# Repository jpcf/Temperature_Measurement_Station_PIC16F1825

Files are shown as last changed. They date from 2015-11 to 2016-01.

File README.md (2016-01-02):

## Temperature Measurement Station

Electronic Systems class Final Project. Consists of a Temperature/HeartRate monitor based on the PIC16F1825 uController. It uses a Nokia5110 LCD matrix as a means to display.

On the `include` folder, you can find a library that interfaces the display (`lib_LCD_Nokia5110`) and another for the 1-Wire Temperature Sensor (`ds18b20`). We also included a library that performs memory tests on all three memory types: RAM, ROM and EEPROM (` lib_memtest_PIC16F1825`).

You are free to use this code in your projects, but **please refer the authors**, *José Fonseca* (me) and *Carlos Ferreira*, from the **University of Porto, Portugal**.

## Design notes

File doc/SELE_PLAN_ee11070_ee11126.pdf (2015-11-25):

# Fingertip Heartrate Measurement

## Carlos Ferreira (ee11070), Jos´e Fonseca (ee11126)

26-10-2015

The envisaged system will measure the heartrate using an infrared measurement sensor, the TCRT1000. The system’s main components are a TCRT1000 sensor, analog circuits, an 8-pin microcontroller, three 7-segment displays and shift-registers.

## 1 Project Overview

The TCRT1000 sensor outputs a current proportional to the infrared light, reflected by the blood. This way, everytime that there is a heartbeat, this reflection will be higher due to the higher concentration of blood. After this, the resulting waveform will be high-pass filtered to enhance the voltage peak that represents the heartbeat. This peak will be fed to a monostable 555 timer that, every time it is triggered by this peak, will produce a voltage pulse with a fixed duration, which will be captured by one of the micro-controller’s General Purpouse Input/Outputs (GPIO).
The microcontroller will then process the incoming pulses and evaluate the inter-arrival time, and extrapolate the heartbeat from this information. Then, at fixed intervals, it will compute a value for the heartrate, and output each one of the 3 decimal digits (since a person’s heartbeat is generally between 60-200 beats per minute, we only need 3 digits to represent it) to three 7-segment displays. Each 7-segment display will have a shift-register that will keep the value stored in its intermediate memory, and they will be arranged in a daisy-chain fashion, connected to the MISO and MOSI interfaces of the microcontroller.
This arrangement can be better understood by observing the following figure.
TCRT1000 | High-Pass Filter

555 Monostable
Trigger (Pulse Generator)

GPIO
(Input)

MOSI

GPIO
(Output) MISO

uController

Shift Register | Shift Register | Shift Register

Data In

Data In | Data In
Data Out | Data Out
Data out OutputEn | OutputEn | OutputEn

7-Segment
LCD
(CENTS)

7-Segment
LCD
(DECS)

7-Segment
LCD
(UNITS)
7 | 7 | 7

## 2 Lab and Industrial prototype

The laboratory prototype will be developed using a PIC32MX120F032B from Microchip in a breadboard. This is already tested because it was used on other projects, so it won’t be necessary to debug this configuration (the basic PIC32MX120F032B IC and the discrete components necessary). The power supply is already designed (basically and 9v battery and a 3.3 voltage regulator). The analog circuitry will be mounted on the breadboard and we will test it with an oscilloscope to ensure correct behaviour.
The industrial prototype will use an 8-pin PIC16F18313 microcontroller. The power supply will be identical to the one used in the laboratory prototype. The remaining hardware is also ‘portable’, and, for that reason, it will be the same from the lab prototype.

## 3 Development Approach

Stages of Development

The first step will be the design of the analog circuitry that serves as the basis of the interface. This will include the dimensioning of the high-pass filter, calculating the appropriate gain to appropriately trigger the 555 timer – even when the pulse is relatively dim – and to calculate the appropriate 555 pulse duration, and the corresponding values for C and R that will define it.
This pulse will first actuate a LED and, after we are sure that is works appropriately, we will develop the microcontroller-side software, and debug the calculated heart-rate values, transferring them to a computer via its UART interface.
After this is done, we can start to develop the software for the 7-segment drivers, and the associated daisy-chain configuration, again debugging using the UART interface.
When both of these halves are complete, we will merge them together, and check if the system works as a whole. After this, we will finally develop a suite of software tests that will be embedded in the project, and will be run everytime the system is startup.

Software used and Organization Policies

We will use MPLABX as the Integrated Development Environment to develop the software for the microcontrollers, and also as a debugging platform. Cadsoft’s Eagle will be used to keep the project schematic updated, and to develop the final tentative board for a hypothetical final product.
Everytime we commit to a hardware component placement/design, we will update the Eagle schematic; this way, we will have a quick reference if some wire is inadvertly disconnected, and it will also be easier to design the PCB board at the end of the project. We will also keep a Git-Hub folder with all the schematics and source code of our project, where you will be able to keep up with the work that we are developing.

## 4 Component List

Component | Price (per unit) | # of units
TCRT1000 (http://pt.farnell.com/vishay-siliconix/tcrt1000/sensor-optical-4mm-transistor/dp/1470064) (IR Sensor) | e1.06 | 2
LD1117V33-DG (http://www.digikey.com/product-detail/en/LD1117V33-DG/497-12822-5-ND/3028553) (3.3 voltage regulator) | e0.71 | 2
PIC16F18313 (http://www.digikey.com/product-detail/en/PIC16F18313-I%2FP/PIC16F18313-I%2FP-ND/5033490) (microcontroller) | e0.69 | 2
LM555CNNS/NOPB-ND (http://www.digikey.com/product-detail/en/LM555CN%2FNOPB/LM555CNNS%2FNOPB-ND/6575) (555 timer) | e1.10 | 2
74HCT595N (http://eu.mouser.com/ProductDetail/NXP-Semiconductors/74HCT595N112/?qs=me8TqzrmIYXtbHcL2Ztc%2fQ%3d%3d) (shift-register) | e1.78 | 4
TDSL5160 (http://eu.mouser.com/ProductDetail/Vishay-Semiconductors/TDSL5160/) (7 segment display) | e1.90 | 3

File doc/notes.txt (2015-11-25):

--> A conexão a IR_CATHODE (pino 3 [4]) não é necessária, é feita internamente (cf página 5 da D.S.)

--> Os pinos 10-12 NÃO DEVEM ESTAR LIGADOS!

--> O address do dispositivo é fixo, e é o 0010_011x_b, em que 'x' é o bit
que define o modo de leitura ou escrita. Anyway, o endereço do 'escravo' é 0x13 

--> O registo dos resultados está no registo 7 e 8 (endereços 0x87 e 0x88), que
contém, respectivamente, o byte MAIS significativo (Reg7) e o MENOS significativo (Reg8)
--> O registo da ambient light está no registo 5 e 6 (endereçoes 0x85 e 0x86).

--> A stop condition entre write e reads consecutivos NÃO É obrigatória.
--> Também funciona  com repeated start!
--> Para ler registos subsequentes, não é necessário endereçá-los: basta endereçar o primeiro, e o register counter é incrementado automaticamente a cada comando de Read para o slave.

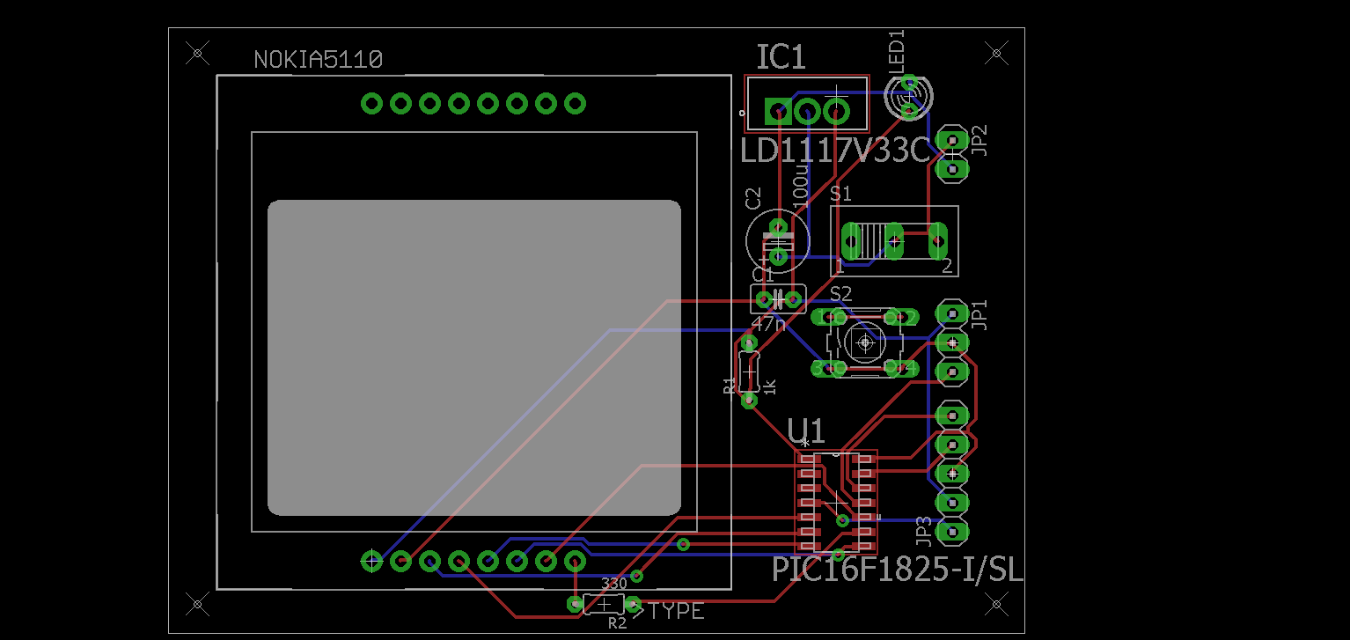
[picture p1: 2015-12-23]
sch/seleBoard.png

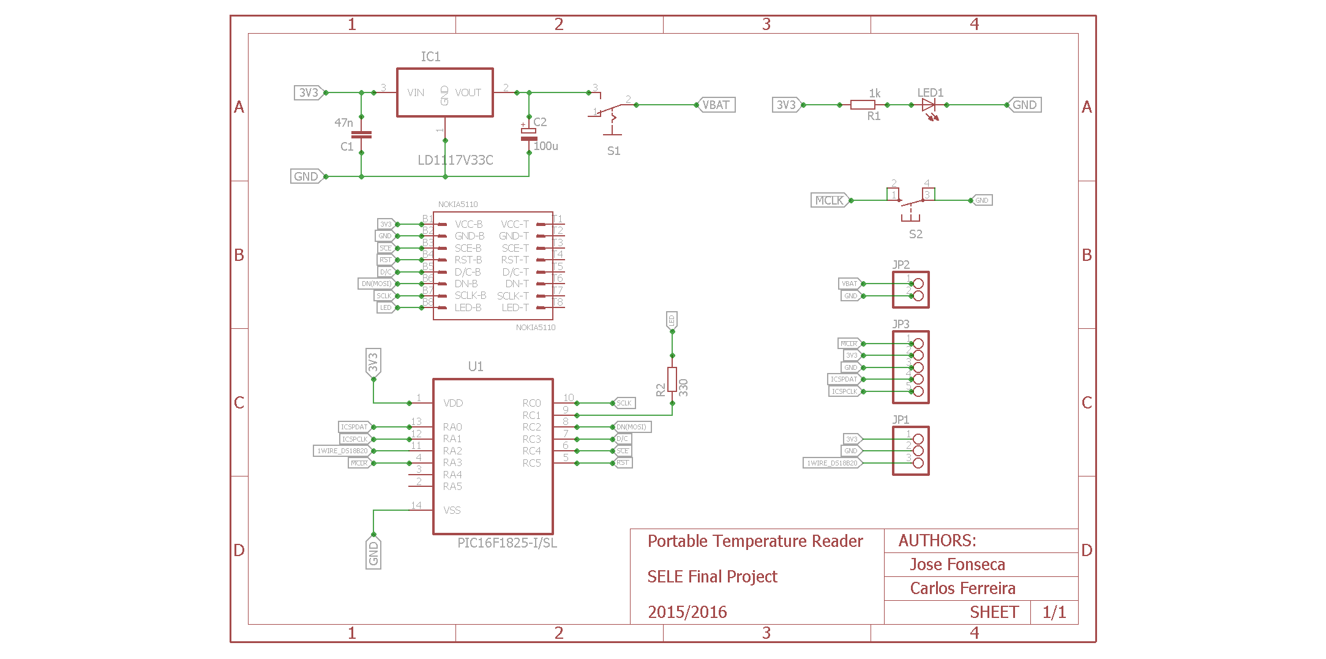
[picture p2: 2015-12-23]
sch/seleSchem.png

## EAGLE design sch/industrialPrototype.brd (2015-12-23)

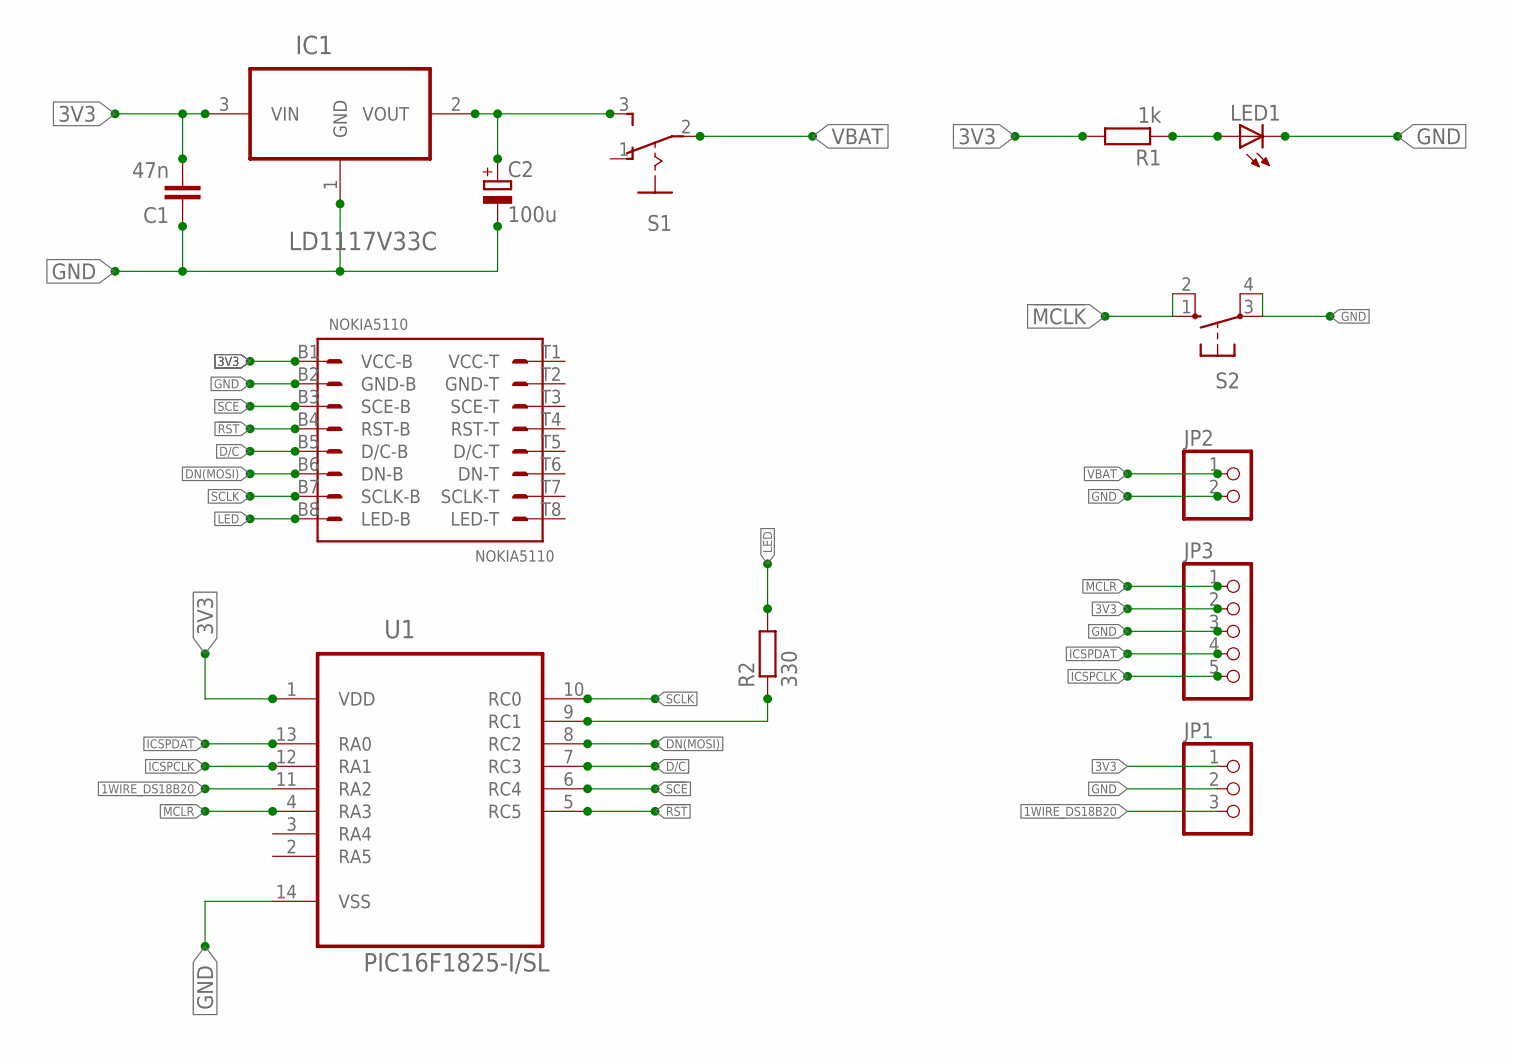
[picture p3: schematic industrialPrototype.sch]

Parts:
C1: 47n; C025-025X050
C2: 100u; E2,5-6
IC1: LD1117V33C; TO254P482X1024X3124-3P
JP1: PINHD-1X3; 1X03
JP2: PINHD-1X2; 1X02
JP3: PINHD-1X5; 1X05
LED1: LED3MM
NOKIA5110: NOKIA5110
R1: 1k; 0204/5
R2: 330; 0204/5
S1: 255SB
S2: 10-XX; B3F-10XX
U1: PIC16F1825-I/SL; SOIC127P600X175-14N

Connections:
1WIRE_DS18B20: JP1.3, U1.11 (RA2)
3V3: C1.2, IC1.3 (VIN), JP1.1, JP3.2, NOKIA5110.B1 (VCC-B), R1.2, U1.1 (VDD)
!MCLK!: S2.1 (S), S2.2 (S1)
!MCLR!: JP3.1, U1.4 (RA3)
!RST!: NOKIA5110.B4 (RST-B), U1.5 (RC5)
!SCE!: NOKIA5110.B3 (SCE-B), U1.6 (RC4)
D/C: NOKIA5110.B5 (D/C-B), U1.7 (RC3)
DN(MOSI): NOKIA5110.B6 (DN-B), U1.8 (RC2)
GND: C1.1, C2.-, IC1.1 (GND), JP1.2, JP2.2, JP3.3, LED1.K (C), NOKIA5110.B2 (GND-B), S2.3, S2.4 (P1), U1.14 (VSS)
ICSPCLK: JP3.5, U1.12 (RA1)
ICSPDAT: JP3.4, U1.13 (RA0)
LED: NOKIA5110.B8 (LED-B), R2.2
unnamed: LED1.A, R1.1
unnamed: R2.1, U1.9 (RC1)
SCLK: NOKIA5110.B7 (SCLK-B), U1.10 (RC0)
VBAT: C2.+, IC1.2 (VOUT), JP2.1, S1.2, S1.3 (S)

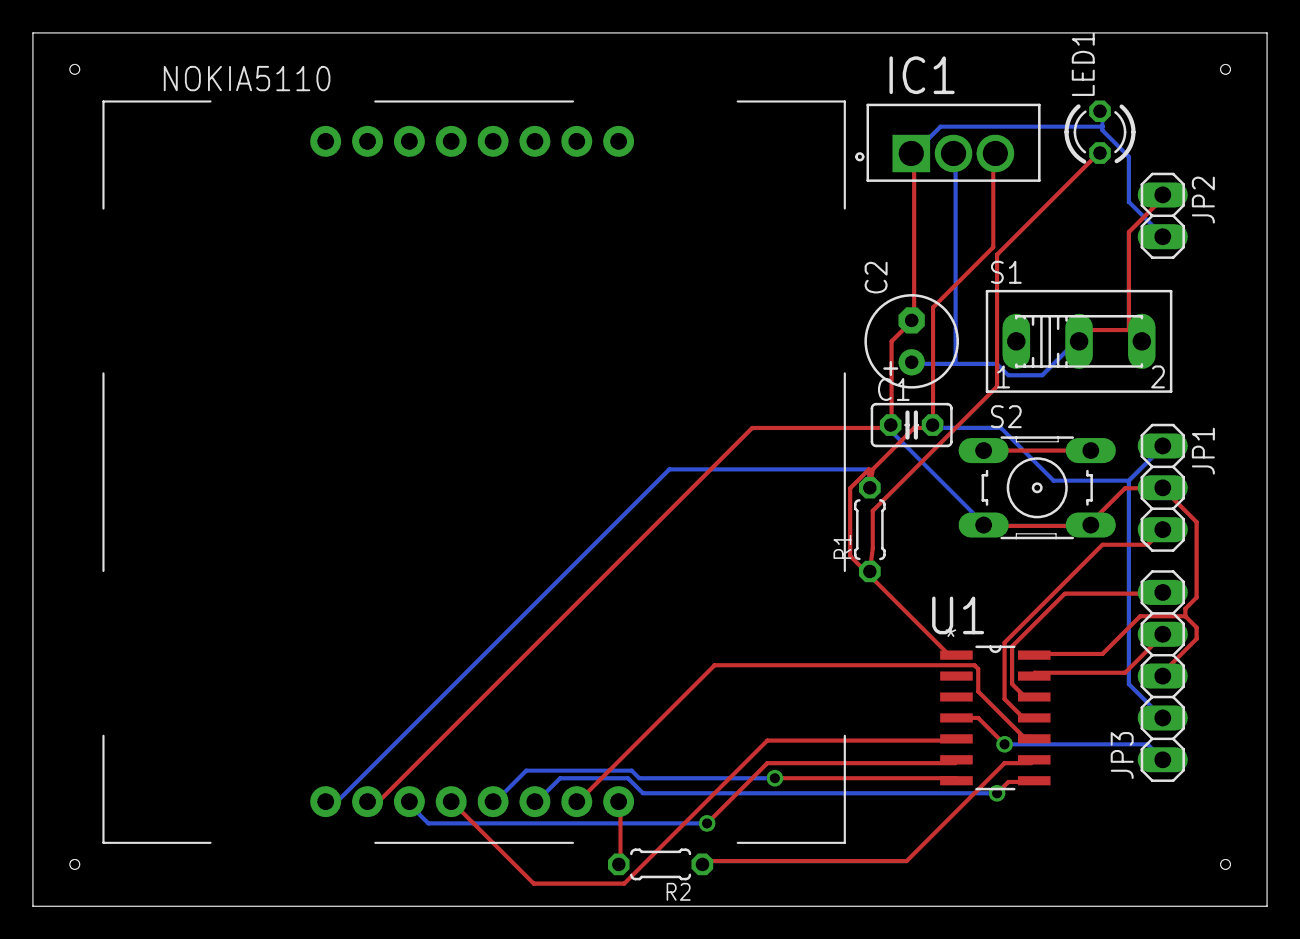
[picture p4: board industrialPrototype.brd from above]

Board: 2 copper layers, 74.9 x 53.0 mm, 13 parts (0 on the bottom side), 16 nets.

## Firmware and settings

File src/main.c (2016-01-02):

/*
Authors: José Pedro Fonseca, Carlos Ferreira, 2015
University of Porto, Portugal
*/

#include <stdio.h>
#include <stdlib.h>
#include <string.h>
#include <stdint.h>
#include <xc.h>
#include "../include/PIC16F1825_configs.h"
#include "../include/ds18b20.h"
#include "../include/lib_LCD_Nokia5110.h"
#include "../include/lib_memtest_PIC16F1825.h"
#include "../include/PIC16F1825_utils.h"

const char IMG[504] = {
0x08,
0xA2,
0x55,
0x08,
0x22,
0x04,
0x29,
0x02,
0x28,
0x12,
0x05,
0x28,
0x02,
0x14,
0x09,
0x22,
0x14,
0x00,
0x00,
0x22,
0x88,
0x55,
0x22,
0x08,
0x22,
0x09,
0x14,
0x22,
0x08,
0x05,
0x12,
0x28,
0x02,
0x29,
0x04,
0x12,
0x00,
0x00,
0xA2,
0x08,
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


int main(int argc, char** argv) {
    
    char tempStr[14];
    LCDcursor cursor;    
    /* ----- Device Initial Config ----- */
    pic16f1825_init();
    
    /* ------ LCD Initial Config ------- */
    initLCD();
    configLCD();
    
    /* ---------- RAM Testing ---------- */
    uint16_t RAMtest = memtest_MARCH_Cmin();
    LATC1 = 1;
    
    clearLCD(&cursor);
    sprintf(tempStr, "Memory Tests:");  
    printlnLCD(tempStr, strlen(tempStr), 2, &cursor);
    
    /* Returns 0x3000 if no Errors, otherwise returns the address of the first error */
    gotoXY(0, cursor.yPos+1);
    cursor.yPos += 1;
    
    if(0x3000 == RAMtest){
        sprintf(tempStr, "RAM Test OK!");  
        printlnLCD(tempStr, strlen(tempStr), 2, &cursor);
    }else {
        sprintf(tempStr, "!RAM @ 0x%04X", RAMtest);
        printlnLCD(tempStr, strlen(tempStr), 2, &cursor);
    }

    /* ---------- ROM Testing ---------- */
    uint8_t ROMtest = memtest_program_mem();
    if(ROMtest){
        sprintf(tempStr, "ROM Test OK!");  
        printlnLCD(tempStr, strlen(tempStr), 2, &cursor); 
    }else {
        sprintf(tempStr, "ROM Error!");  
        printlnLCD(tempStr, strlen(tempStr), 2, &cursor);
    }
    
    /* -------- EEPROM Testing -------- */
    if(memtest_eeprom(NULL)){
        sprintf(tempStr, "EEPROM Test OK!");  
        printlnLCD(tempStr, strlen(tempStr), 2, &cursor);
    }else {
        sprintf(tempStr, "EEPROM Error!");  
        printlnLCD(tempStr, strlen(tempStr), 2, &cursor);
    }
    
    uint8_t turn_on_times = read_eeprom(0);
    
    if(0xFF == turn_on_times) /* By default the EEPROM data in a given address is 0xFF */
        turn_on_times = 1;    /* This is the first time the circuit is powered up */
    else
        turn_on_times++;
    
    write_eeprom(0,turn_on_times);
    write_eeprom(255,turn_on_times ); /* update the checksum (last address of EEPROM) */
    
    sprintf(tempStr, "The circuit was powered %d times",turn_on_times);  
    printlnLCD(tempStr, strlen(tempStr), 2, &cursor);
    
    __delay_ms(3000);
    printImageLCD(IMG);
    __delay_ms(3000);

    set_precision_ds18b20(PRECISION_12);
    
    while(1){
        start_temp_measure_ds18b20();
        __delay_ms(1000);           /* Wait for temperature measurement */
        sprintf(tempStr, "Temp: %.2f", read_temp_ds18b20());
        gotoXY(0,2);
        cursor.yPos = 2;
        printlnLCD(tempStr, strlen(tempStr), 2, &cursor);
    }

    return (EXIT_SUCCESS);
}

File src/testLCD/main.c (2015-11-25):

#include <stdio.h>
#include <stdlib.h>
#include <stdint.h>
//#include <PIC16F1825.h>
#include <xc.h>

#pragma config WDTE = OFF // This disables the watchdog timer!

#define _XTAL_FREQ 4000000
#define DC    LATC3
#define SCE   LATC4
#define RST   LATC5
#define DIN   LATC2
#define SCK   LATC0

void TIMER2config (unsigned char comparePer, unsigned char preload,
                   unsigned char presc, unsigned char postsc) {
    PR2    = comparePer;  
    TMR2   = preload; 
    T2CON |= postsc | (presc<<3); 
}

void initLCD() {
    // Some initial configs on port C
    ANSELC &= 0x00; // All bits on port C are set to Digital I/O's
    TRISC  &= 0x00; // All bits on Port C are set to Outputs
    APFCON0 |= (1<<5); // Don't use special features on Pin RC3
    APFCON1 |= (1<<2); // Don't use special features on Pin RC3
    
    LATC = 0x00;
    
    // All pins are initialy idle (HIGH), except for DIN
    DC    = 1;
    SCE   = 1;
    RST   = 1;
    DIN   = 0;
    SCK   = 0;
    
    // Initial reset to the device
    __delay_ms(300);
    RST = 0;
    __delay_ms(300);
    RST = 1;
}

void sendByteLCD(unsigned char* buf, unsigned char dataCommand) {
    DC  = dataCommand;
    SCK = 0;
    __delay_us(1);
    SCE = 0;
    __delay_us(1);
    
    for(int i=0; i < 8; i++) {
        SCK = 0; // Clock goes idle
        
        // Since we send the MSB first, we mask bit 8 and we send its logical value
        (*buf) & 0b10000000 ? DIN = 1 : DIN = 0;  
        
        // Rising Edge of the Clock
        __delay_us(1);
        SCK = 1;
        __delay_us(1);
        
        // We shift the next bit
        (*buf) = ((*buf)<<1);
    }
    
    SCK = 0;
}

void printCharLCD(char c) {

}

void CLOCKconfig() {
    OSCCON  = 0x6A; //Sets the internal oscillator fosc = 4 MHz
    OSCSTAT = 0x00;
    OSCTUNE = 0x00;
}

void main(void) {
    
    unsigned char buf;
    
    CLOCKconfig();
    initLCD();
    
    buf = 0x21;
    sendByteLCD(&buf, 0);
    buf = 0xC0; // Set the Operation Voltage to a good value
    sendByteLCD(&buf, 0);
    buf = 0x07; // Set the TempCoef to 4
    sendByteLCD(&buf, 0);
    buf = 0x13; // Set Bias bits BSx. This way we get Mux of 1:48
    sendByteLCD(&buf, 0);
    buf = 0x20; // Normal set of controls
    sendByteLCD(&buf, 0);
    buf = 0x08; // Clears the screen
    sendByteLCD(&buf, 0);
    buf = 0x0C; // Normal Display Mode
    sendByteLCD(&buf, 0);
    
    LATC1 = 1;
    __delay_ms(1000);
    
    while(1) {
        buf = rand() % 256;
        sendByteLCD(&buf, 1);
        __delay_ms(1);
    }
    
}

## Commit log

2015-11-24 First Commit: The first prototype for the README.md file
2015-11-24 The test file for the LCD driver
2015-11-25 Now the LCD completely works, and is able to print data. Need to clean the file, separate the functions to another file, and find a suitable font
2015-11-26 Added font support to the Library, and a function to print a char that partially works
2015-11-28 Changed the testSPI.c file. Now prints the whole alphabet, but somehow starts filling blanks afterwards
2015-11-28 Added support to print lines, and go to a specified address. There are still some issues
2015-11-29 Added further printlnLCD function, and also corrected the pointer issue of the send_N_ByteLCD()
2015-11-29 Now makes use of the printlnLCD, and uses sprintf to format the string
2015-11-29 Now prints in hex format correctly
2015-12-02 Foram adicionados varios ficheiros. pic16f1825_configs .h e respectivo .c pic16f1825_utils.h e respectivo .c ds18b20.h e respectivo .c
    Foi alterado o lib_memtest_pic16f1825.c e respectivo .h em que se adicionou a função que testa a ROM
    Foi também adicionado o ficheiro /src/main.c que contem a funcao main
2015-12-02 ao ao pino usado no 1-wire que agora é o RA2 FOi retirado o _RC2_ dos nomes das funcões 1-wire
2015-12-02 The first sketch of the final executable. Only missing the integration with OneWire readings
    [main.c]
2015-12-03 Improved the main file and the graphics library. Still missing the sensor integration
    [main.c]
2015-12-03 Corrigido bug do teste da ROM
    [main.c]
2015-12-13 Foi adicionado o teste da EEPROM Foram adicionadas as funcoes eeprom_read e eeprom_write Foi adaptado o main para utilizar as novas funçoes
2015-12-15 Added the schematic. Still missing connections to temp sensor and other
    [industrialPrototype.sch]
2015-12-15 Schematic almost finished. Only temp sensor header missing
    [industrialPrototype.brd, industrialPrototype.sch]
2015-12-15 Added Programming Header. Placed components on PCB. Routing still has to be done
    [industrialPrototype.brd, industrialPrototype.sch]
2015-12-16 Added the screen and did the auto-route. Labels still need to be fixed
    [industrialPrototype.sch]
2015-12-18 Added the Temperature Sensor Socket
    [industrialPrototype.brd, industrialPrototype.sch]
2015-12-23 Final Version of the Schematic and Board
    [industrialPrototype.brd, industrialPrototype.sch]
